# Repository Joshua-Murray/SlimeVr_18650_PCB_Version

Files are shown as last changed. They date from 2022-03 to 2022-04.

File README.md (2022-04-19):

# SlimeVr_18650_PCB_Version
This repository contains all the files for the PCB and the case designed with this PCB in mind. It also contains a detailed instructions on the assembly of the PCB and the case.

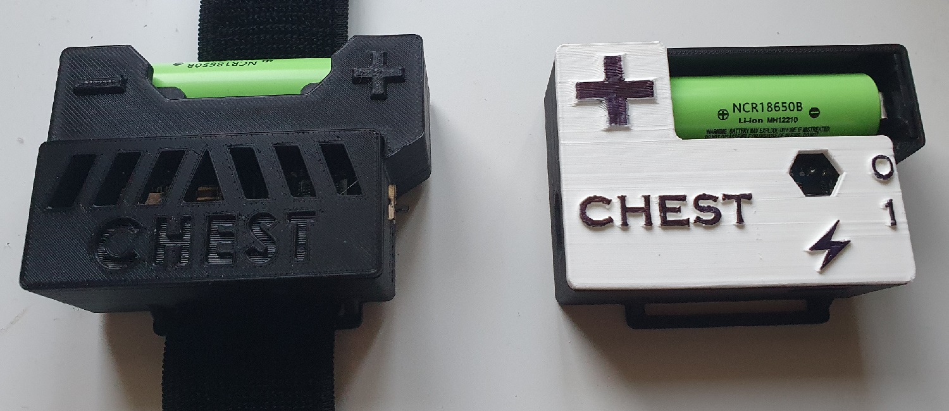
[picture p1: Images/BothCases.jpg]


# Sections
-   Parts and Setup
-   PCB Related Information
- 	Case Related Information
- 	Assembly Information

# Parts and Setup
The parts used for this PCB can be found in the [official Components list](https://docs.slimevr.dev/diy/components-guide.html) and [Schematic](https://docs.slimevr.dev/diy/tracker-schematics.html).
This PCB is compatible with any 3.3V IMU which is smaller than the following maximum dimensions 28mm by 18mm.
The following parts are used in the PCB:
- D1 Mini.
- TP4056 Charge Board (Any connection).
- SPDT Slide Switch (SS12D00G3).
- Any 3.3V IMU under the max dimension 28mm by 18mm.
- 1N5817 Charge Diodes.
	Note for those not using it: Bridge the diode connections from the  positive output to the centre connections.
- (Optional) 180K Ohm resistor for battery sense.
- 3.7V Battery.

For those who who want a case and are using 18650 batteries for the tracker, there are 2 cases using this PCB found in the case files folder. (Additional information below)

# PCB Related Information
The Gerbal file for the PCB can be found in the PCB files folder along with an image of the schematic.
Additionally the project for this PCB can be found at the following links with or without the Aux connector:

PCB with Aux connection: https://easyeda.com/editor#id=22acdfc2081e44a4a4d110a4ab3e7e97

PCB without Aux connection: https://easyeda.com/editor#id=266cc1c912134b10b92cc5d7d849ca76

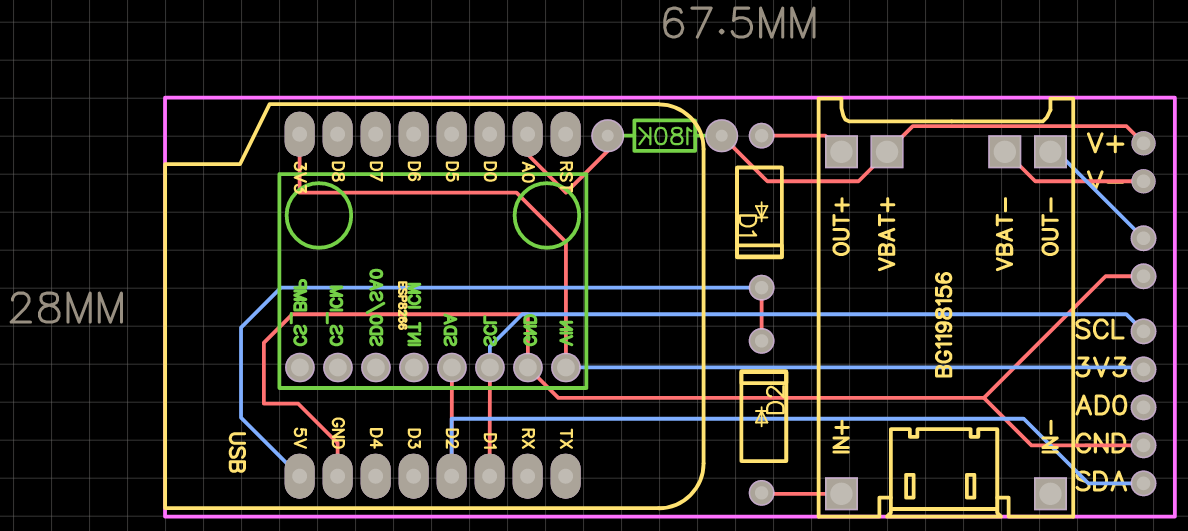
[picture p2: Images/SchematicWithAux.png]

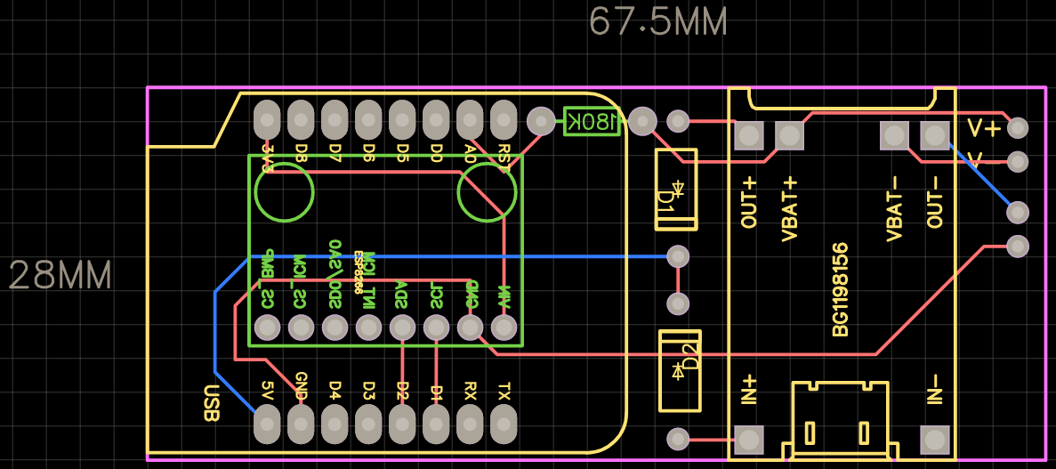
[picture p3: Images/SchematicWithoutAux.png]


## PCB Ordering
The steps for ordering a PCB is very simple and straight forward as seen below.
- Step 1: Download the Gerbal files for the PCB of your choice.
- Step 2: Go to a PCB manufacturing site, for demonstration purposes JLCPCB will be used found here: https://jlcpcb.com/

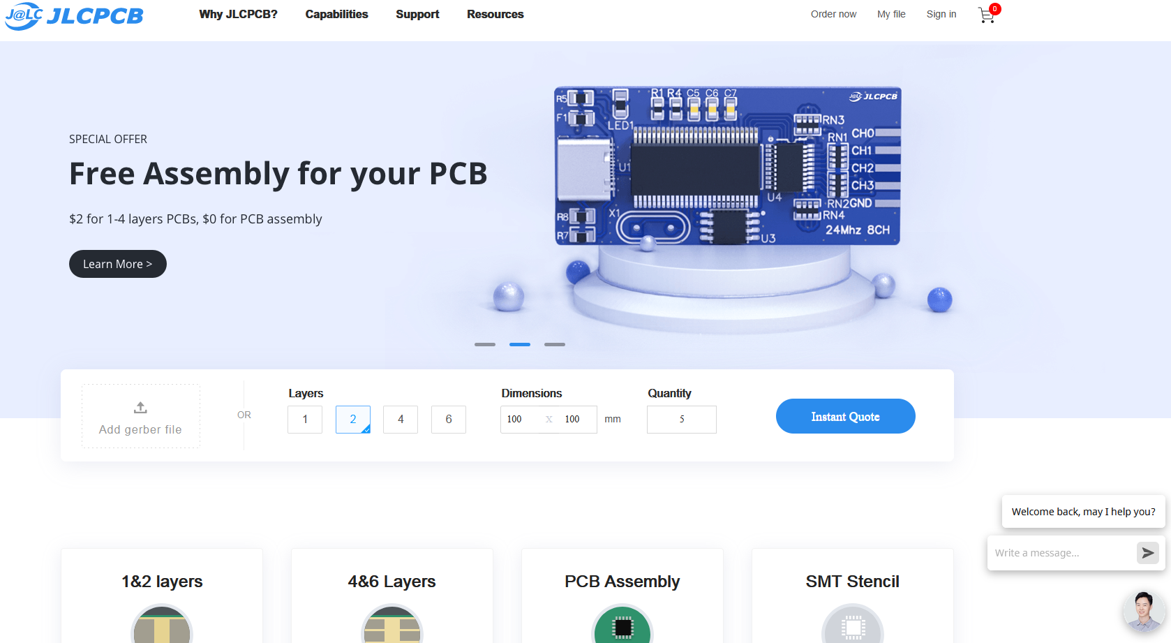
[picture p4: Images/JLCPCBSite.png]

- Step 3: Upload the Gerbal zip file.
- Step 4: Inspect the following settings are correct (see image) and adjust any of the cosmetic options to your preference.

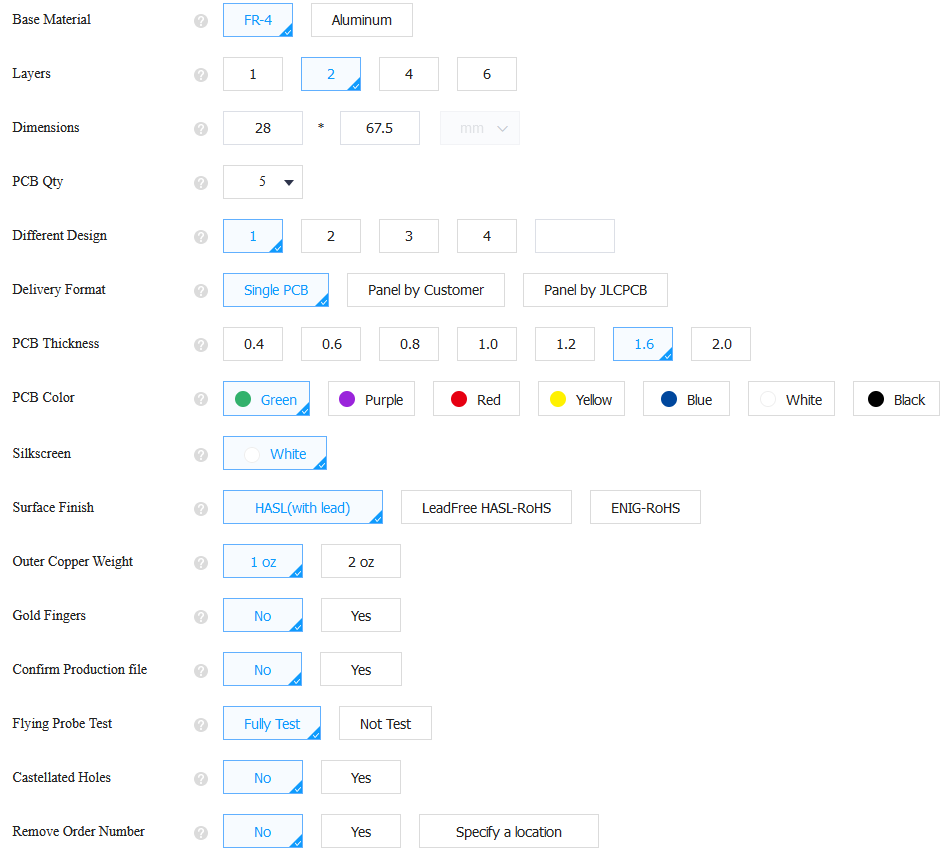
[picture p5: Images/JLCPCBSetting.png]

- Step 5: Pay and wait for it to arrive.

# Case Related Information
This section referes to the cases designed for the PCB and found in the Case files folder. Both of the cases have been designed in SolidWorks.

## Case V:
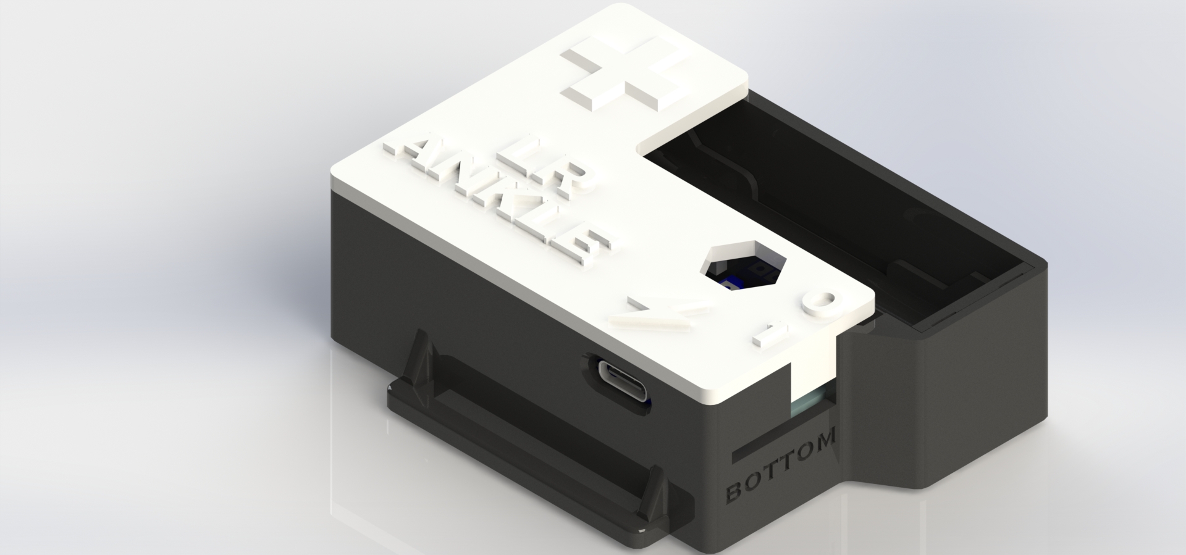
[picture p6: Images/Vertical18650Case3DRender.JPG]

The STL files for 3D printing this case can be found in the "Case Files / Vertical 18650 Battery Mount" folder along with the original files for easy modifications if you choose to do so.

## Case H:
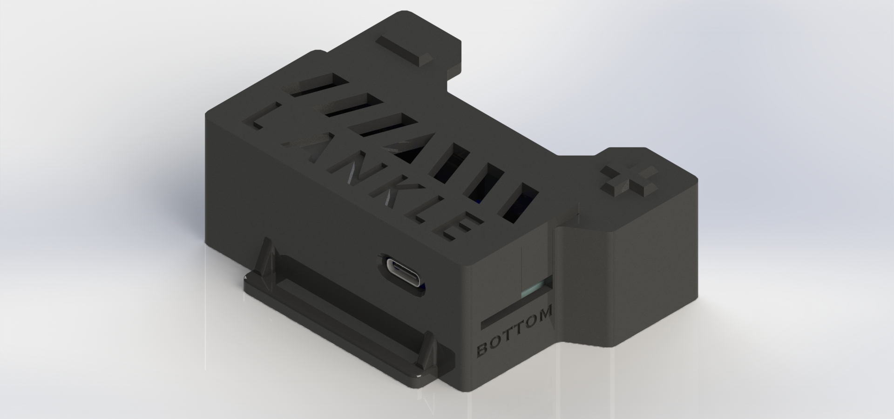
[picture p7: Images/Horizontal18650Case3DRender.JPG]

The STL files for 3D printing this case can be found in the "Case Files / Horizontal 18650 Battery Mount" folder along with the original files for easy modifications if you choose to do so.

## Extension:
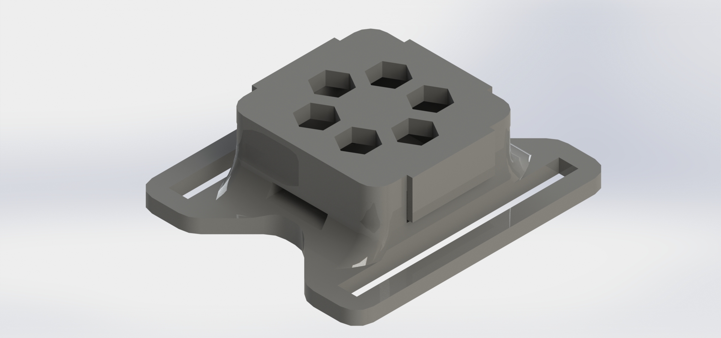
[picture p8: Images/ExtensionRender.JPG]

The STL files for 3D printing this case can be found in the "Case Files / Extension Case" folder along with the original files for easy modifications if you choose to do so.
Note: This extension case is compatible with all IMUs within 28mm by 18mm dimensions, if there are request for larger IMUs they would be added.

## 3D printing the case
The following demonstration for preparing each STL file will be shown in PrusaSlicer, ensure that the if there is supports used to match the images provided.
All of the case files can be printed at 0.2mm layer height.

- For the vertical battery mount case model use supports where the Aux cables exit the case.
- For the lid model, use supports for all overhanging material.

- For the horizontal battery mount case model use supports where the Aux cables exit the case and where the 18650 battery holder will be held.
- For the horizontal lid model, does not require any support material.

- The Extension models does not require any support material.

PCB Assembly Instructions
For the instructions below MPU6050 will be used, however any IMU using 3.3V input, match the first 4 pins and within 28mm by 18mm. Diodes are not required but the positive output must be bridged with a wire.
The battery sense resistor is optional, within this instructions a higher watt resistor will be used, 1/4 watt also works.

Below are all the electrical parts required to build a tracker, the parts within the marked area are for the extension tracker.
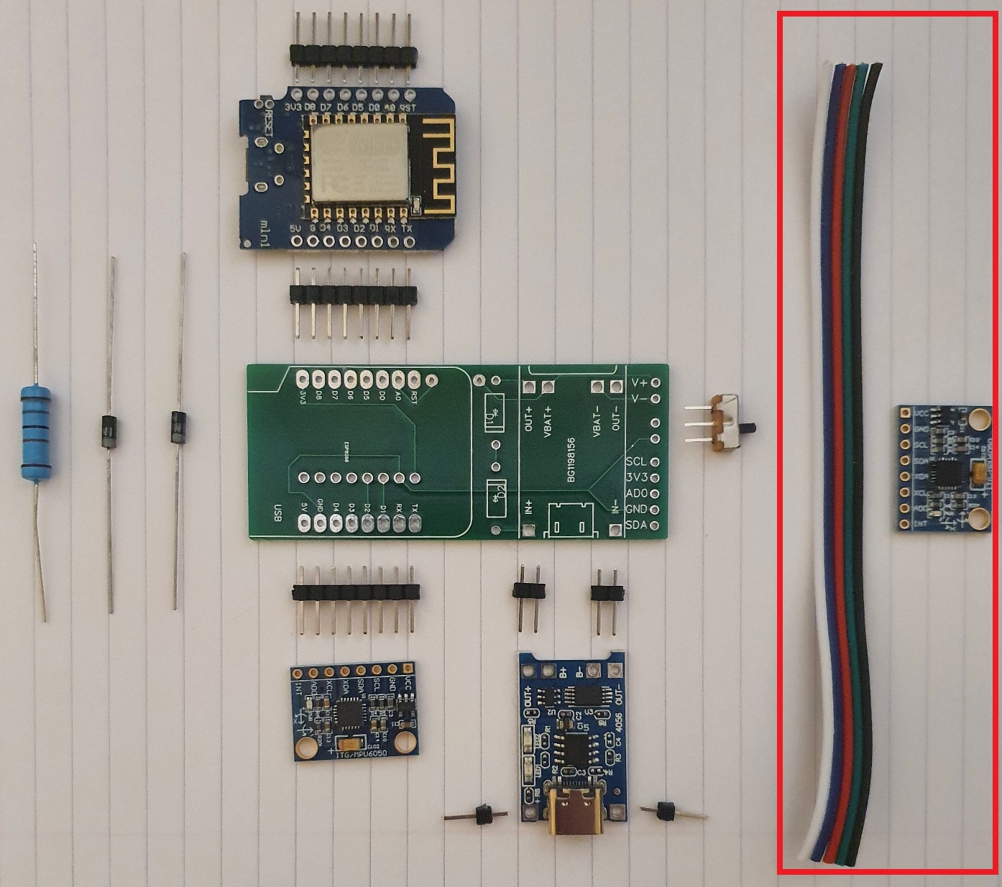
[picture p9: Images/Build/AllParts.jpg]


Step 1:

Solder the diodes in their spaces as shown in the picture (Grey strip pointing to the centre) and cut off the excess.

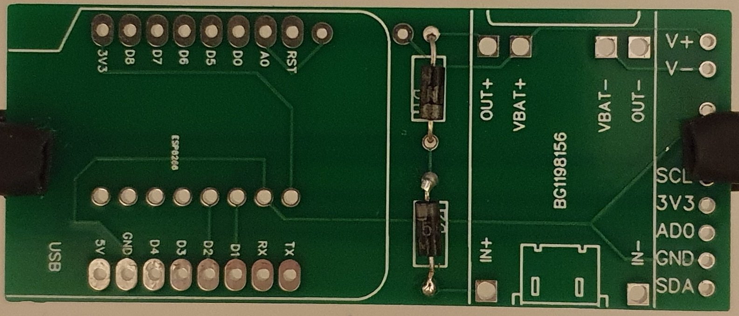
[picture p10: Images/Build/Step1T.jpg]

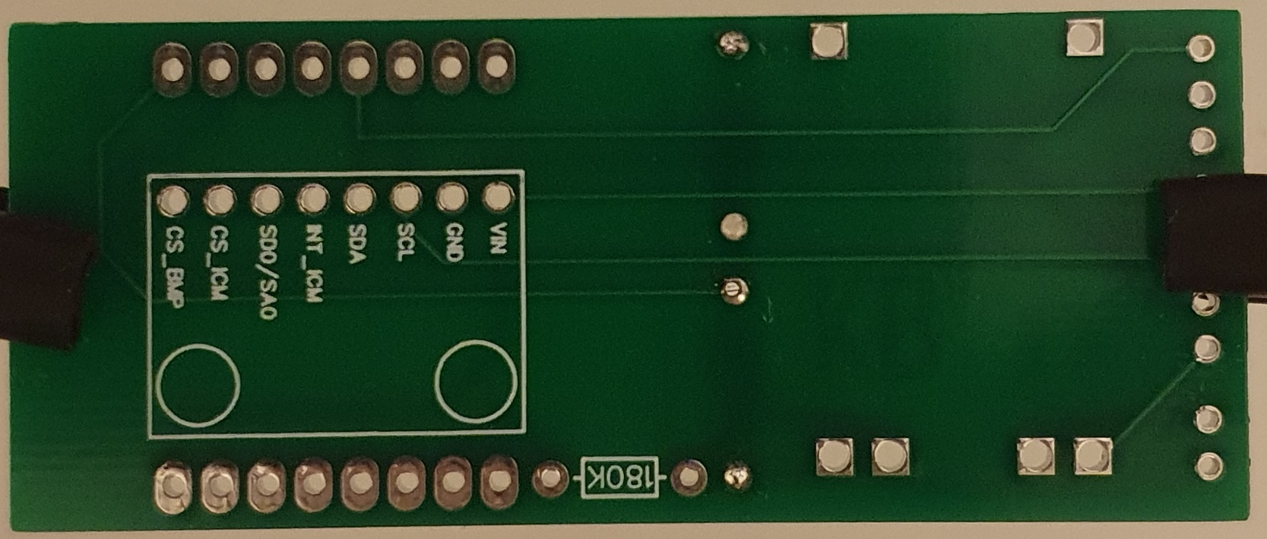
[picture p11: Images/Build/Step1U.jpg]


Step 2:

Solder the pins used for the TP4056 in the spaces as shown in the picture.

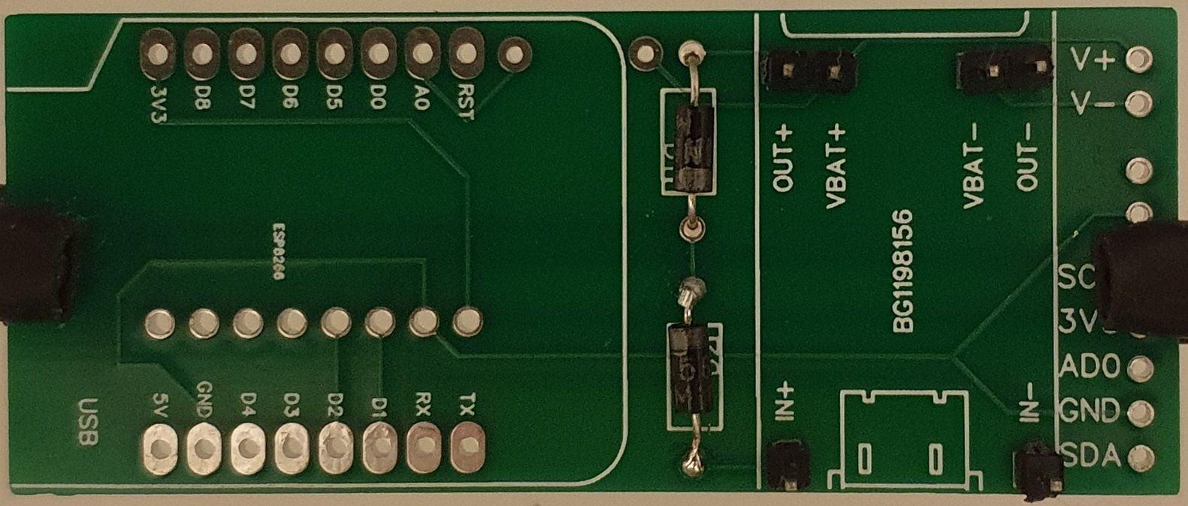
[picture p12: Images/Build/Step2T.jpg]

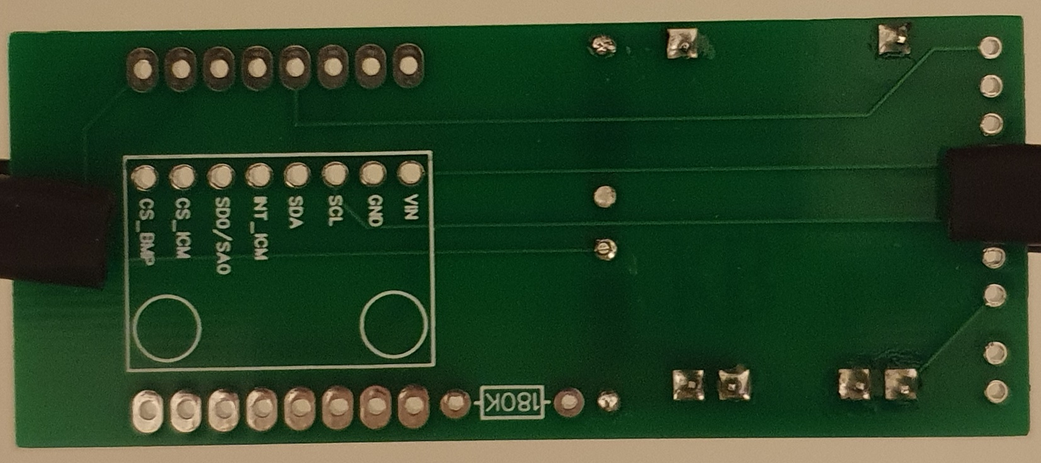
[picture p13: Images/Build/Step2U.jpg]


Step 3:

Solder the TP4056 on the pins from step 2 as shown in the picture and cut off the excess.

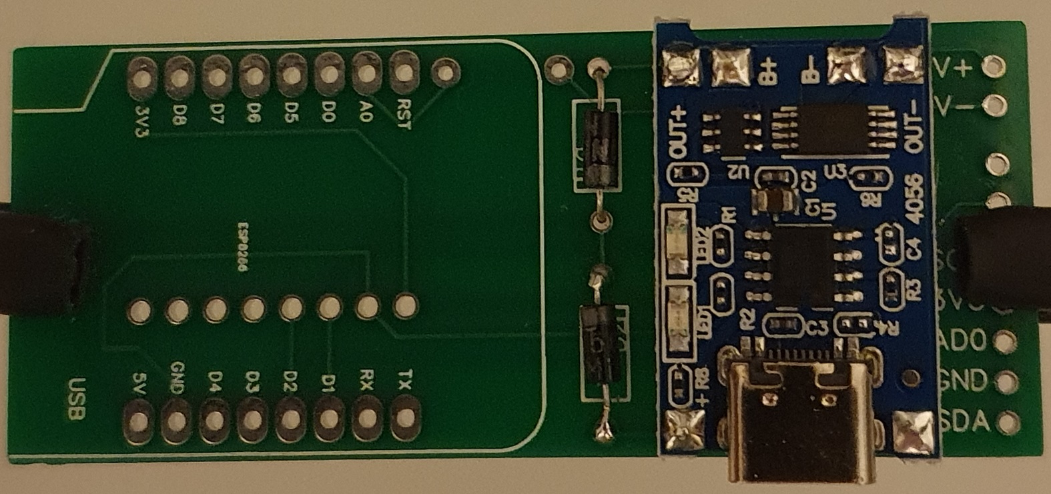
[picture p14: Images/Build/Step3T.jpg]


Step 4:

Solder the pins used for the D1 Mini in the spaces as shown in the picture.

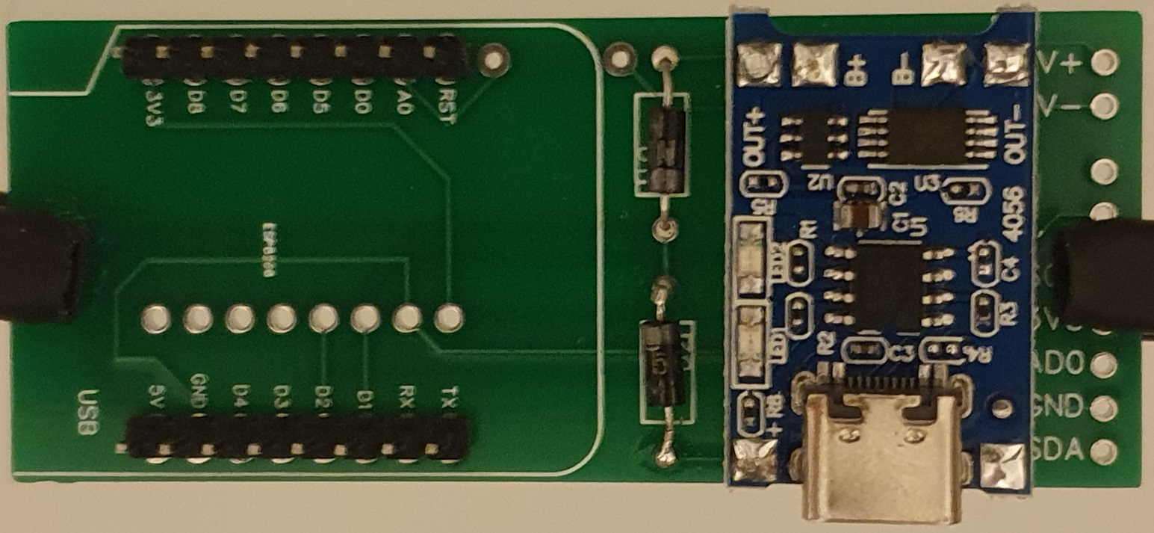
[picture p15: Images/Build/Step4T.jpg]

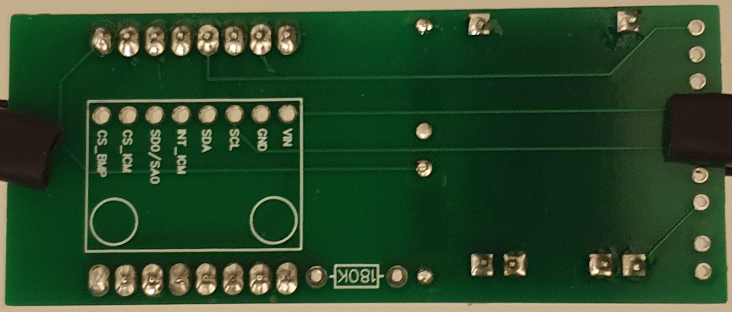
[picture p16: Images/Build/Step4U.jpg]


Step 5:

Solder the pins used for the IMU in the spaces as shown in the picture only VCC, GND, SCL, SDA are required, the rest are optional.

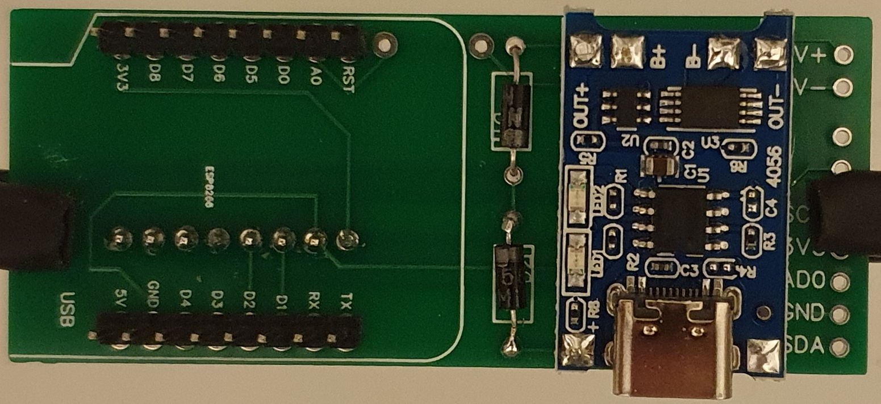
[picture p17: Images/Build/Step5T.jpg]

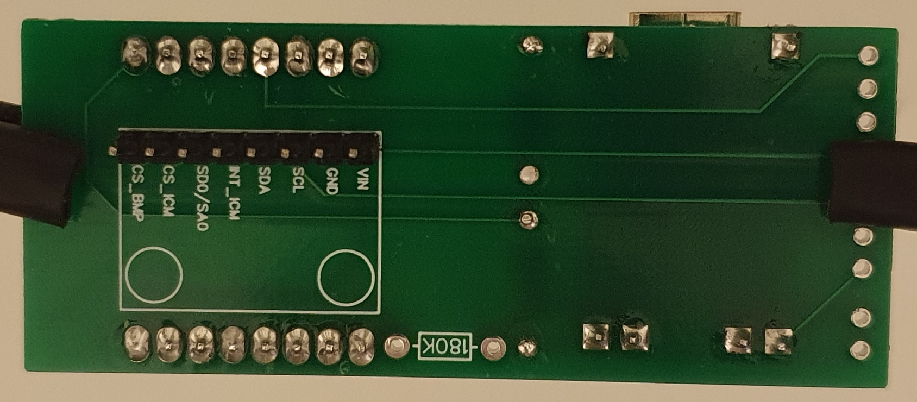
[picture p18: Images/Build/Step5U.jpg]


Step 6 - OPTIONAL:

Solder the battery sense 180K Ohm resistor in the space shown in the picture and cut off the excess.

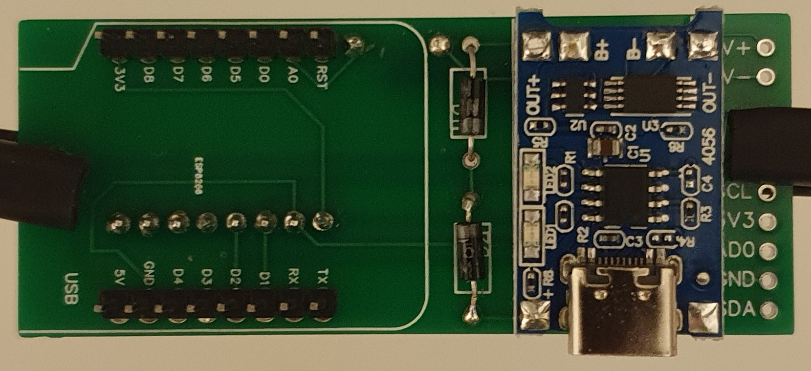
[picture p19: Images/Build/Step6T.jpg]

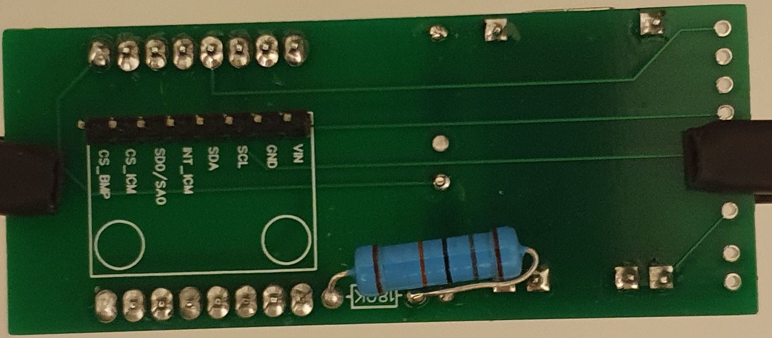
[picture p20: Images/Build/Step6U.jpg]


Step 7:

Solder the D1 Mini on the pins from step 4 as shown in the picture and cut off the excess.

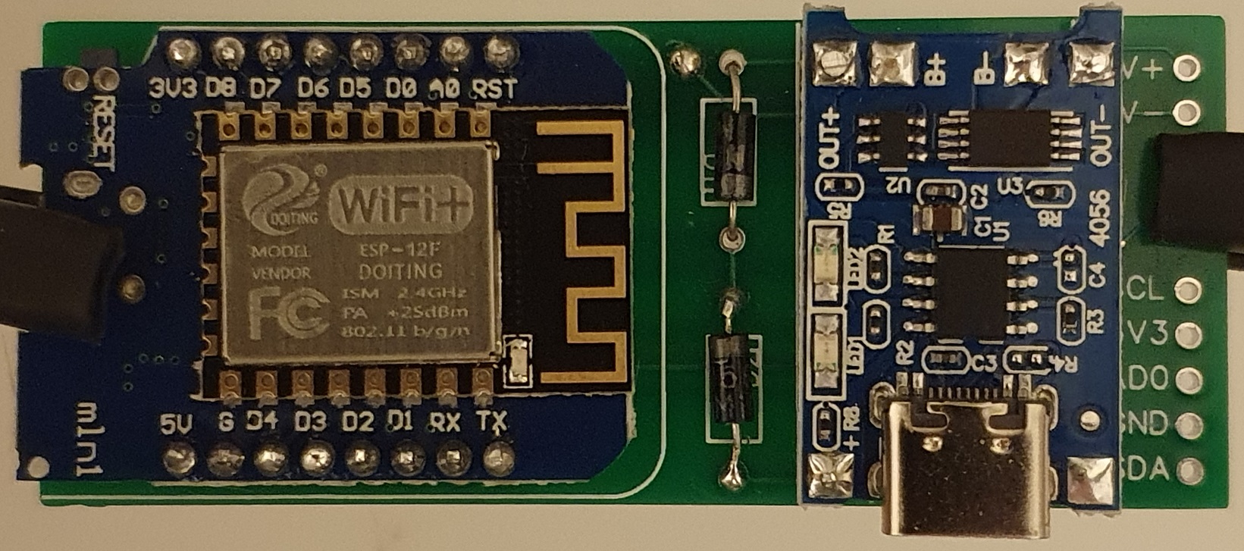
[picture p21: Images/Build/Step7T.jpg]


Step 8:

Solder the IMU on the pins from step 5 as shown in the picture and cut off the excess. Ensure that the IMU remains parallel to the PCB, this could be achieved by using unused pin headers.

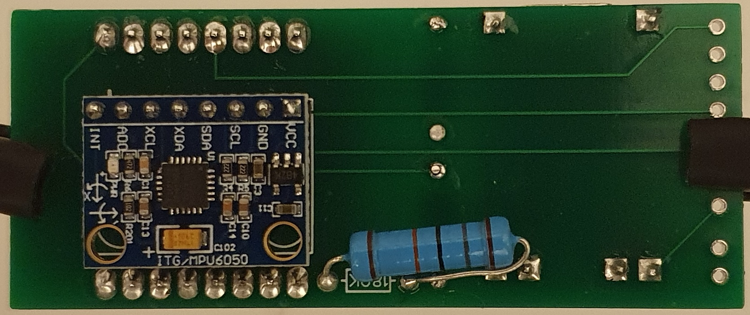
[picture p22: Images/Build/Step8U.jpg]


Step 9:

Cut one of the outside pins of the switch and then bend the remaining two in as shown in the picture.

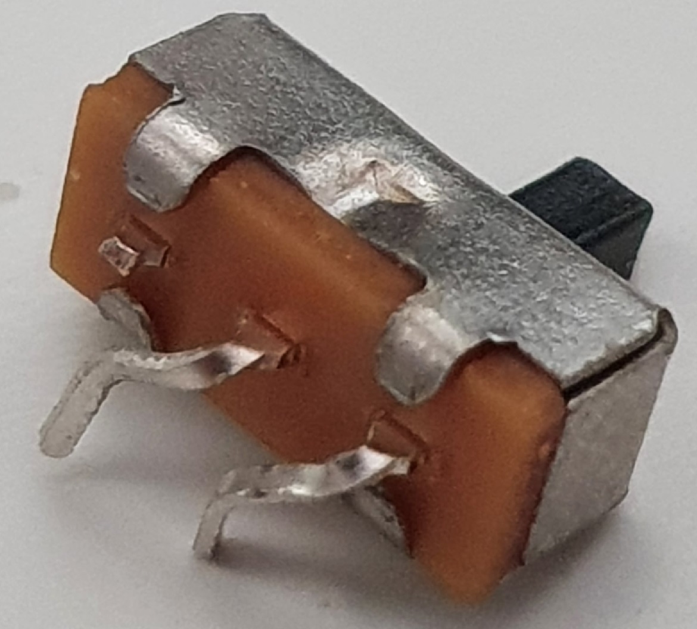
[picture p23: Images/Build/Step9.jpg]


Step 10A - Horizontal 18650 case OPTION 1:

Solder a wire onto each the positive and negative terminals, ensure that the wire for the negative terminal is longer as it will be weaved into the case as shown in the picture, recommended length: Positive 40mm and Negative 90mm. You can coil the positive and negative wire after if you wish to do so. Cut off excess, leave enough wire for moving the PCB when it is attached.

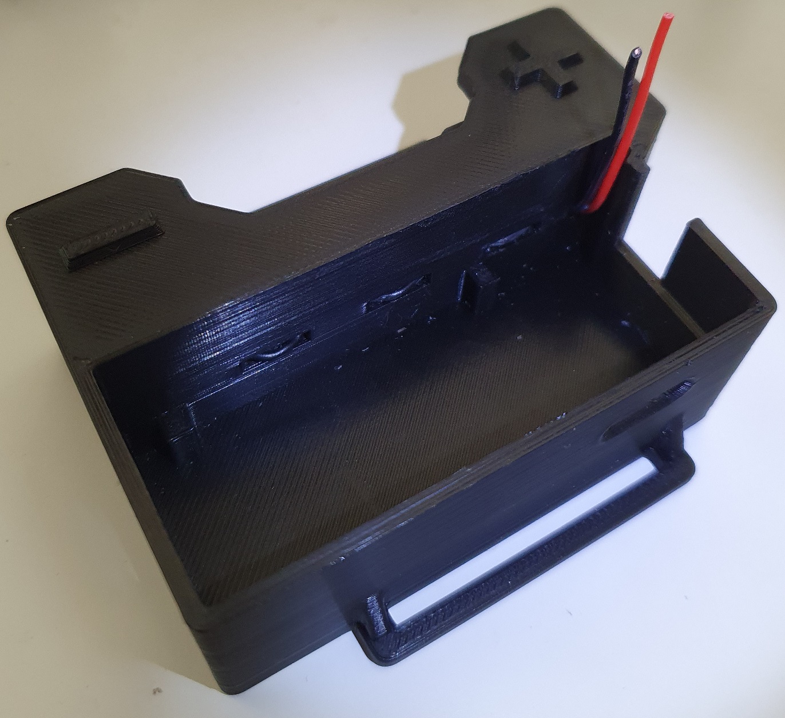
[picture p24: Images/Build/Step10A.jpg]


Step 10B - Vertical 18650 case OPTION 2: 

Solder a wire onto each the positive and negative terminals, ensure that the wire for the positive terminal is longer so it could reach the PCB, recommended length: Positive 90mm and Negative 40mm. You can coil the positive and negative wire after if you wish to do so. Cut off excess, leave enough wire for moving the PCB when it is attached.

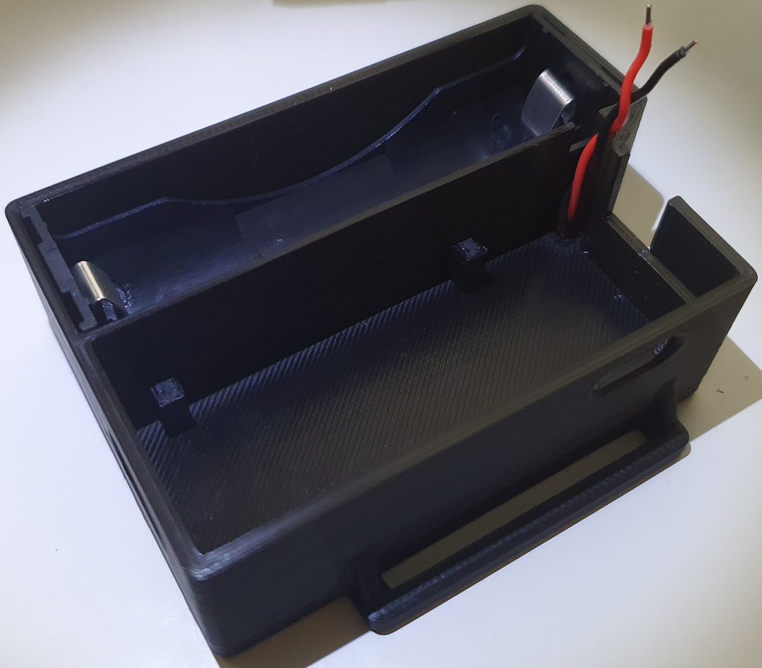
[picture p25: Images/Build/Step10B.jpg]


Step 11 - OPTIONAL EXTENSION:

Solder wires used for the extension tracker as shown in the picture, leave enough wire for movement between trackers. 

Note: Ensure that the ADO is bridged to the 3v3 pin for the extension IMU and ADO bridged to GND for the main IMU the or do so on the IMU side in step 14.

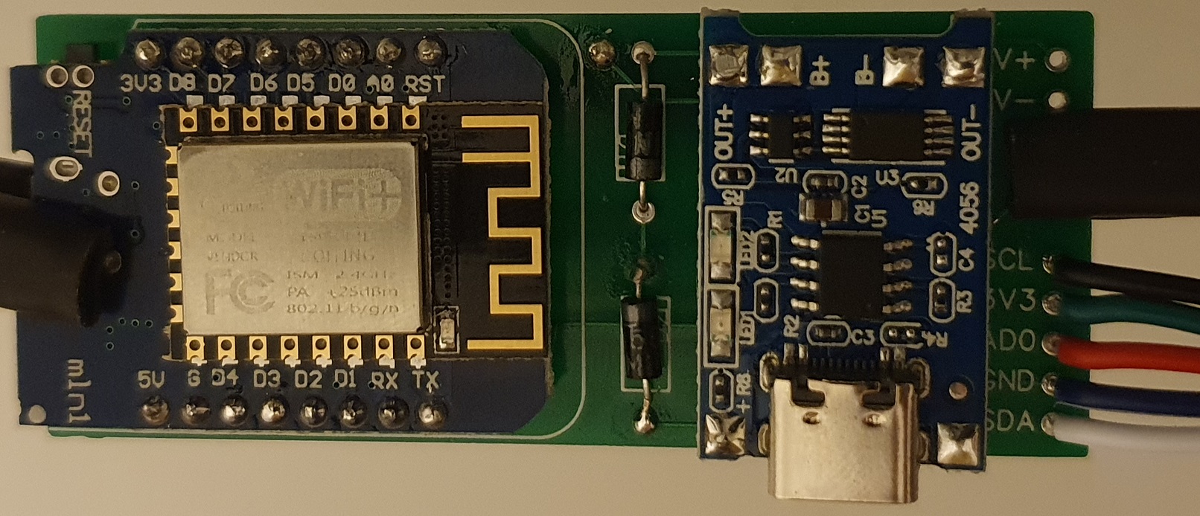
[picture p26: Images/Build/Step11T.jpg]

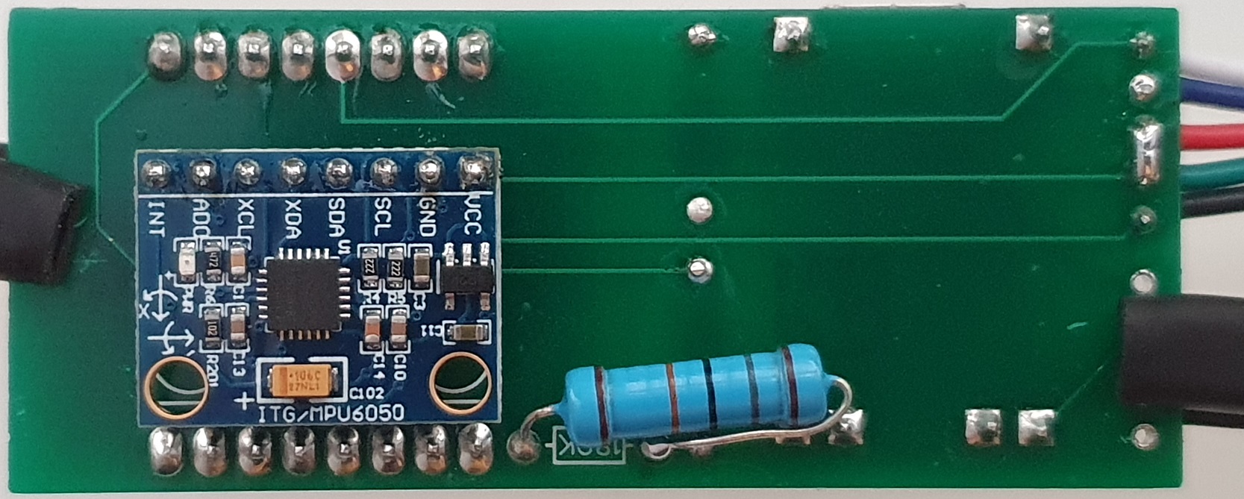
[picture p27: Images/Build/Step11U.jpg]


Step 12:

Note: If there is a extension tracker cables first move them into the slot in the case - the smaller one next to where the switch location.

Insert the PCB into the case, start with the moving TP4056 into its slot and ensure that the batteries wires don't disconnect once the PCB is completely flat inside move on to the next step. This is the same for both cases

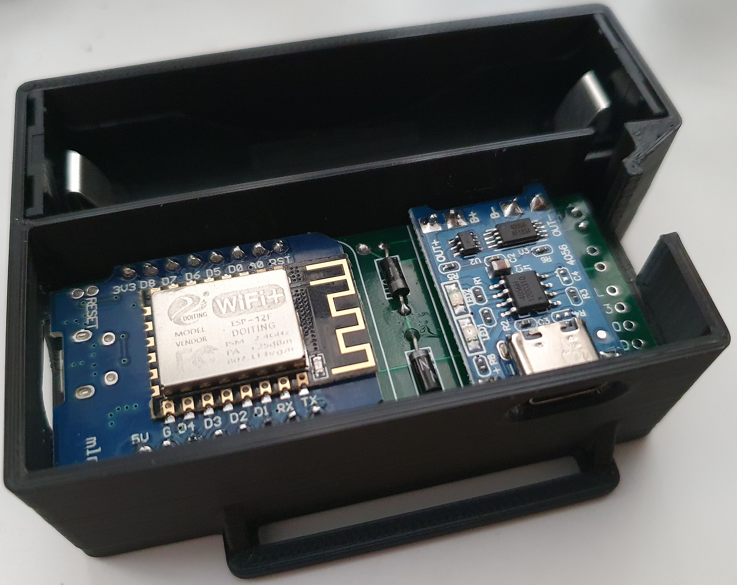
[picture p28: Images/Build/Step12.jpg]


Step 13:

Insert the switch prepared in step 9 into the slot in the case and adjust the pins to go into the PCB holes as shown in the picture. Once satisfied, solder the switch. Put on the corresponding tracker position lid to complete the main unit.

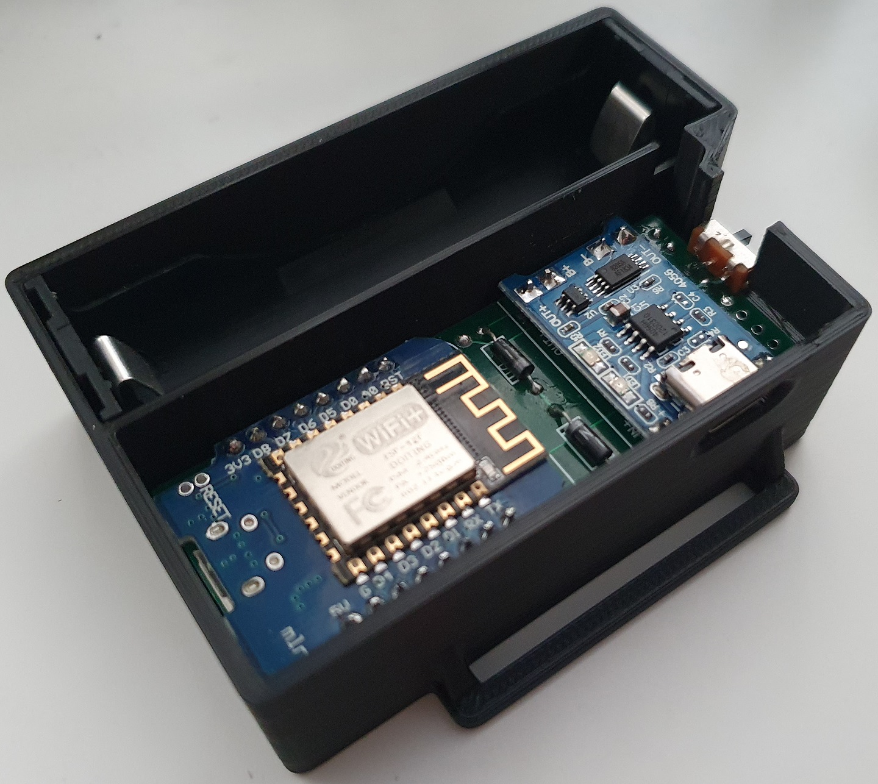
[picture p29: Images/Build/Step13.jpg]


Step 14 - OPTIONAL EXTENSION: 

Using the wires from step 11, put it through the slot in the extension and continue to do so leaving enough room to solder the corresponding wires to the pins of the IMU as shown in the picture.

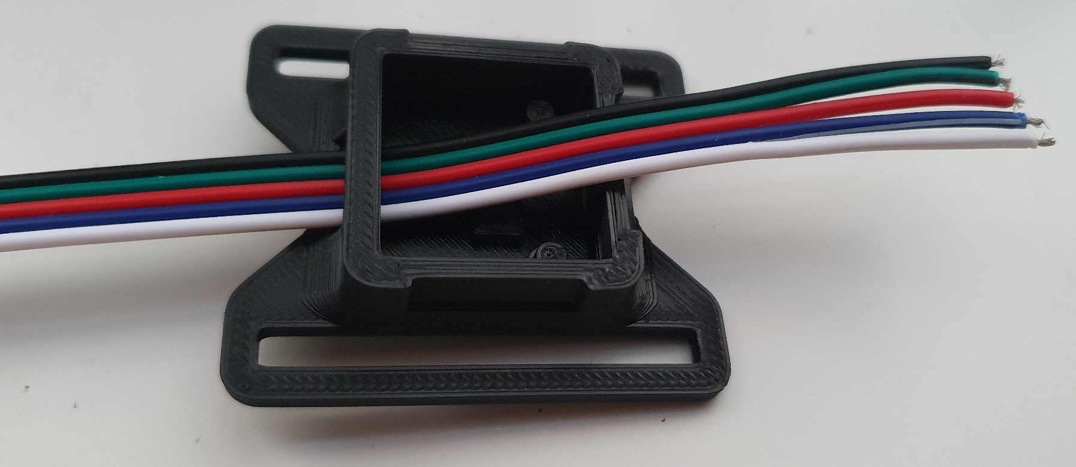
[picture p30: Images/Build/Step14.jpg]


Step 15 - OPTIONAL EXTENSION:

Solder the corresponding wires to the pins of the IMU as shown in the picture - on the underside of the IMU.
Note: Ensure that the ADO is bridge to the 3v3 pin if it has not been done in step 11.

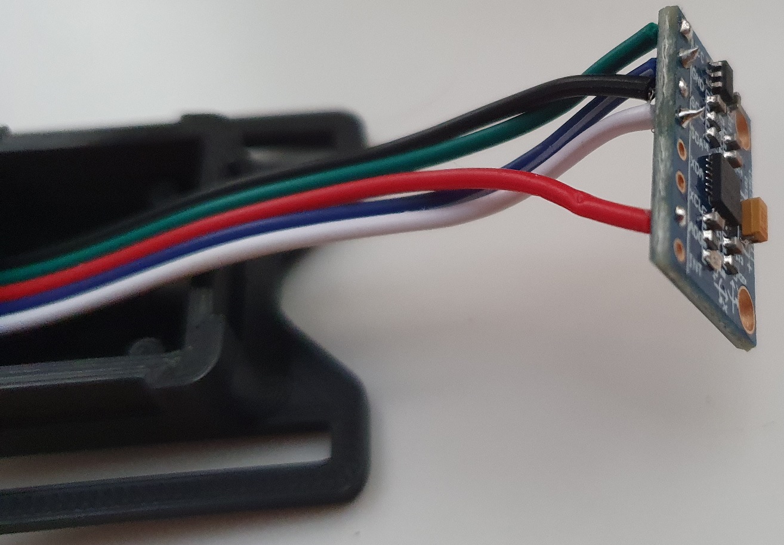
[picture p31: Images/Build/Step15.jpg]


Step 16 - OPTIONAL EXTENSION:

Carefully position the IMU into the extension case, once positioned push it down onto the pins, gently pull cables when required, the IMU should be sitting inside as shown in the picture. Once it is in fully put on the extension lid on to finish the assembly.

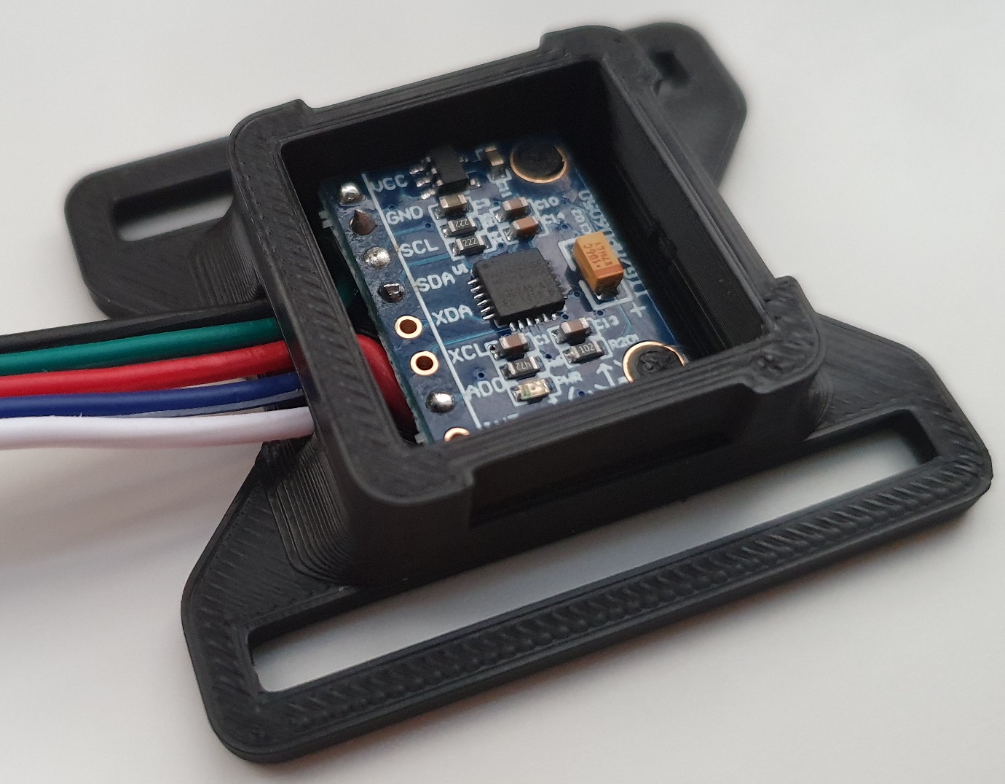
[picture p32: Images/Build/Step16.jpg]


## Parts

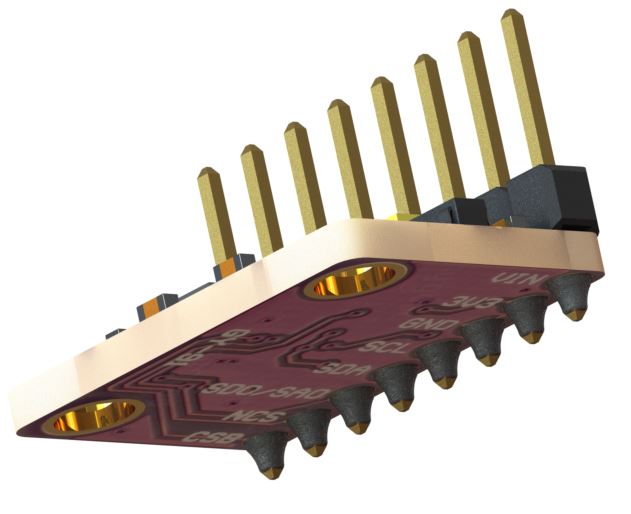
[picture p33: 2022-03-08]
Case Files/Electronic PlaceHolder Parts/GY-91/Renders/GY-91 bot - pins up.JPG

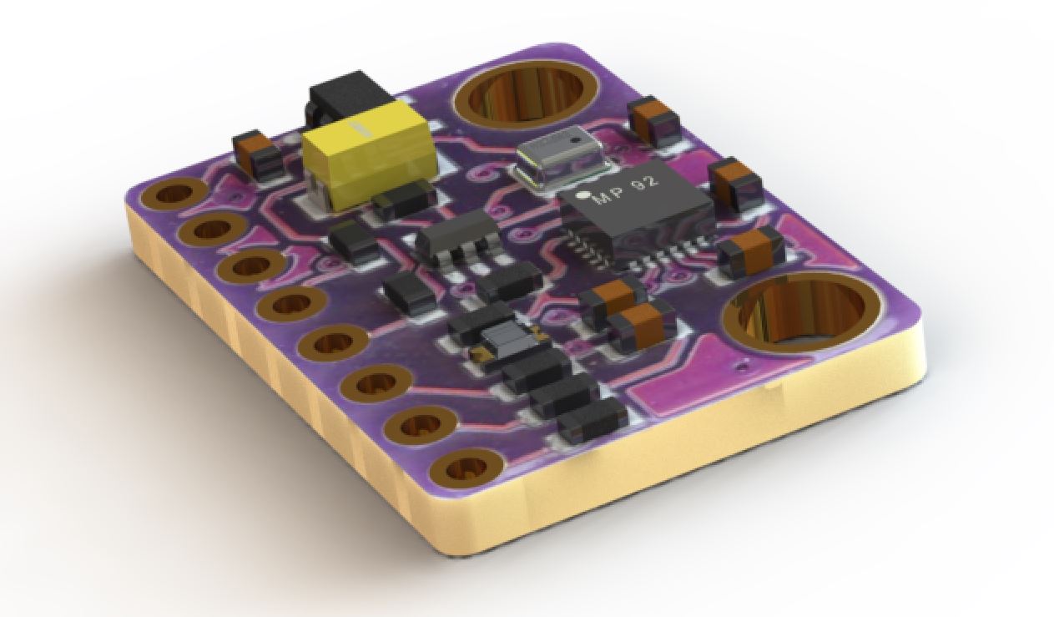
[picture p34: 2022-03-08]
Case Files/Electronic PlaceHolder Parts/GY-91/Renders/GY-91 top - no pins.JPG

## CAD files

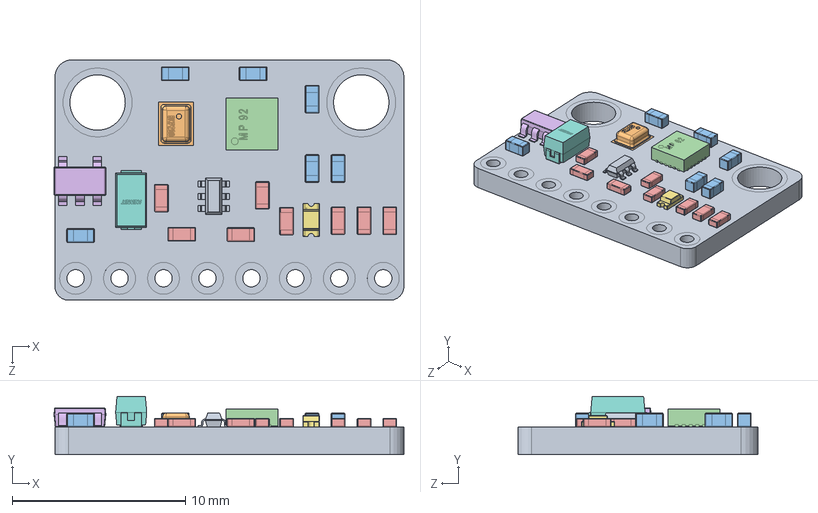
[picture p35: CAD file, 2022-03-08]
Case Files/Electronic PlaceHolder Parts/GY-91/GY-91_MPU9250+BMP280 - Basic.SLDASM
20.2 x 3.37 x 13.9 mm
GY-91 Base
BMP280
cap_603 x 6
MPU9250
res_603 x 8
SOT23-5
Surface Mount Chip LED 3.2x1.6mm
T10uF
SOT23-6-1

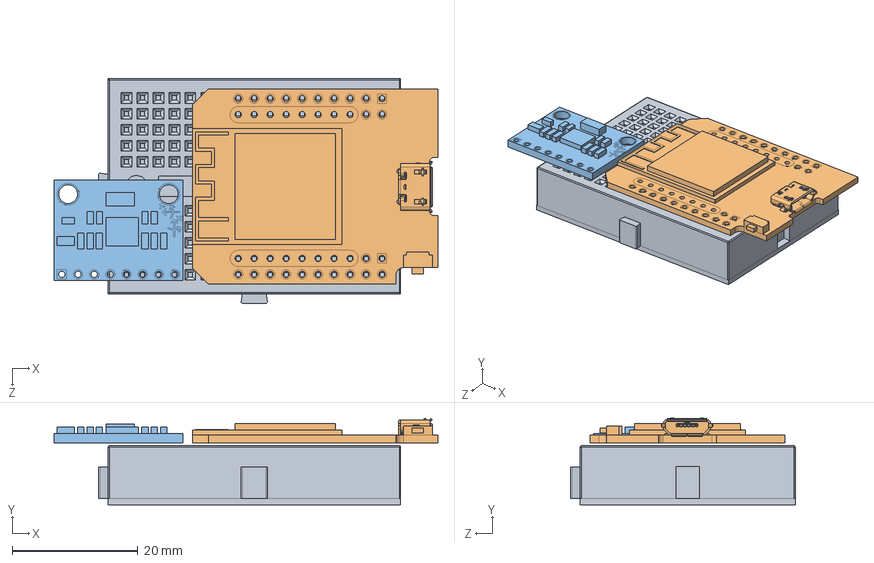
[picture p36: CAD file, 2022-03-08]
Case Files/Electronic PlaceHolder Parts/MPU_MICRO.SLDASM
61.1 x 13.8 x 35.7 mm
Mini-Black Breadboard
Wemos-Mini-D1-ESP32
pcb.step

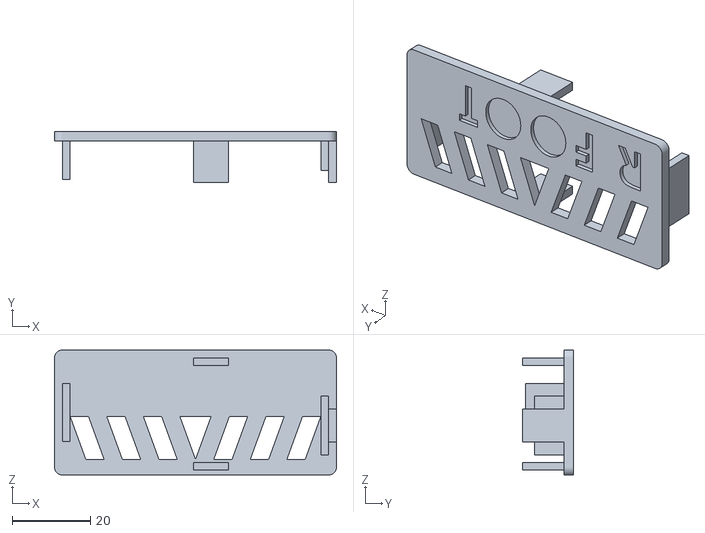
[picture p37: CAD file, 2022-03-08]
Case Files/Horizontal 18650 Battery Mount/_Main_Body_Lid_RFoot.STL
72.1 x 13.1 x 32.0

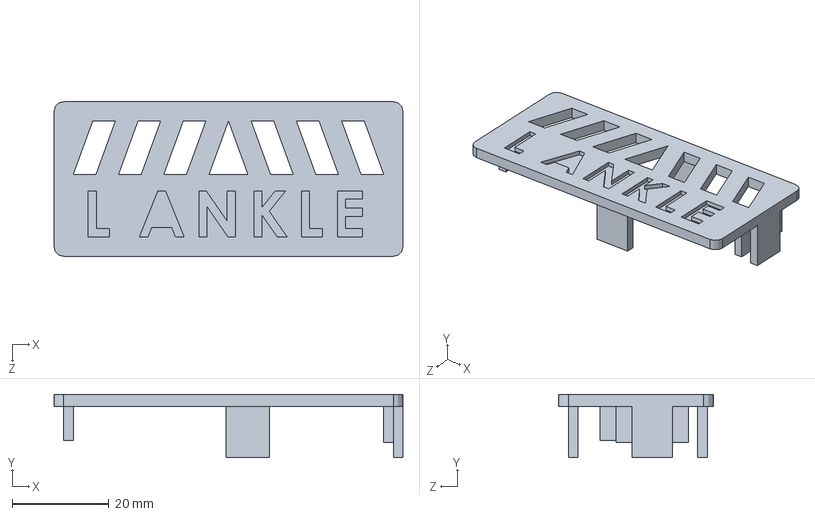
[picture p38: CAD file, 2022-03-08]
Case Files/Horizontal 18650 Battery Mount/Original Files/Main_Body_Lid.SLDPRT
72.1 x 13.1 x 32.0 mm

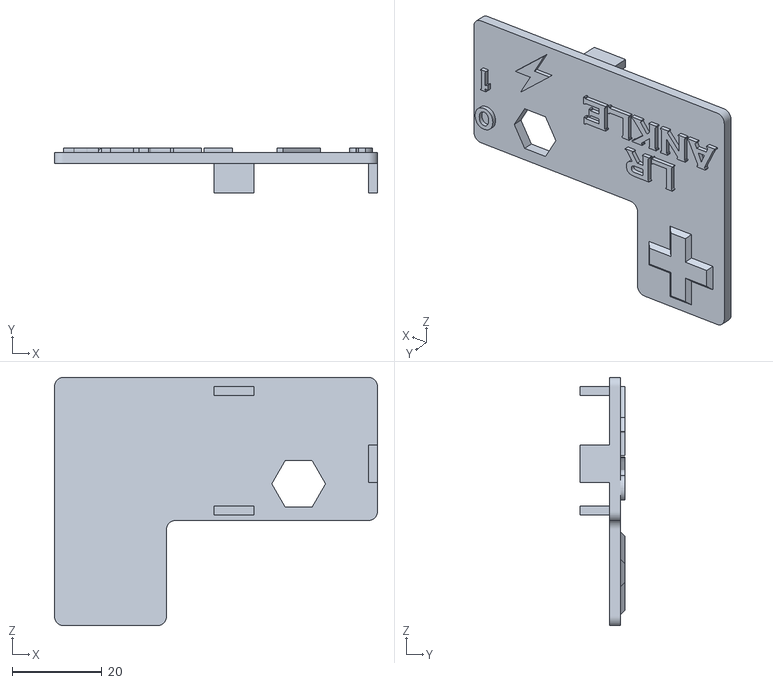
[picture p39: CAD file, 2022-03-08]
Case Files/Vertical 18650 Battery Mount/Main_Body_Lid_Ankle.STL
72.1 x 10.1 x 55.4

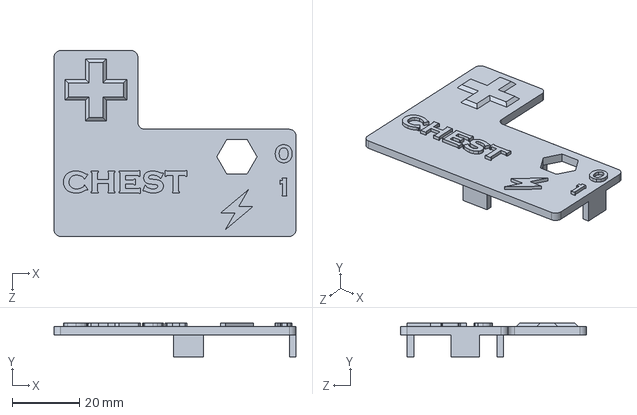
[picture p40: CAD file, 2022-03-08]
Case Files/Vertical 18650 Battery Mount/Original Files/Main_Body_Lid_Chest.SLDPRT
72.1 x 10.1 x 55.4 mm

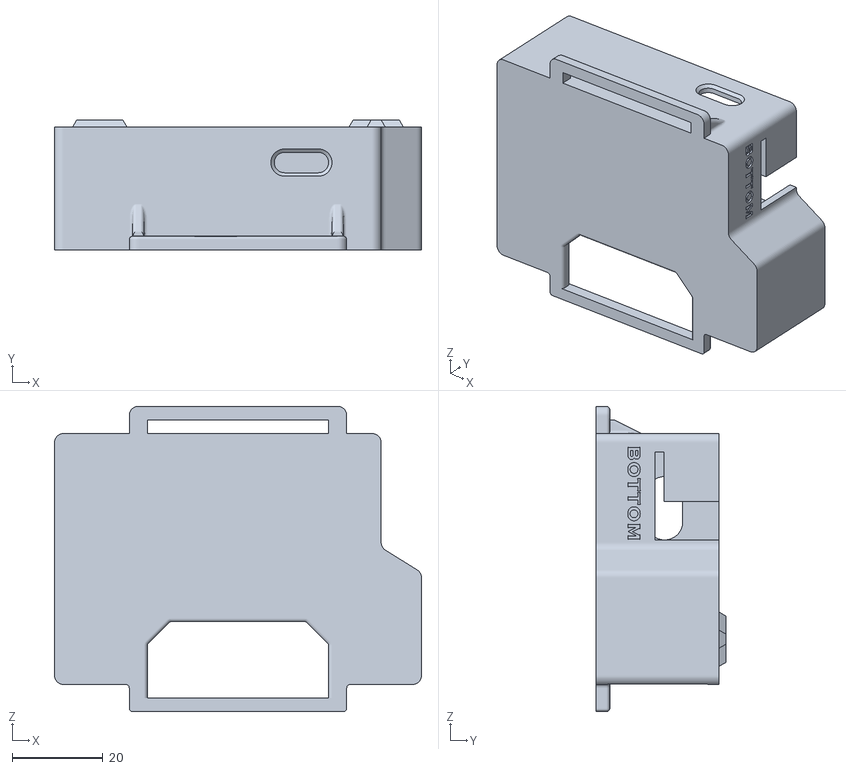
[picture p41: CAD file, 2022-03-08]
Case Files/Horizontal 18650 Battery Mount/_Main_Body.STL
81.0 x 28.6 x 67.4

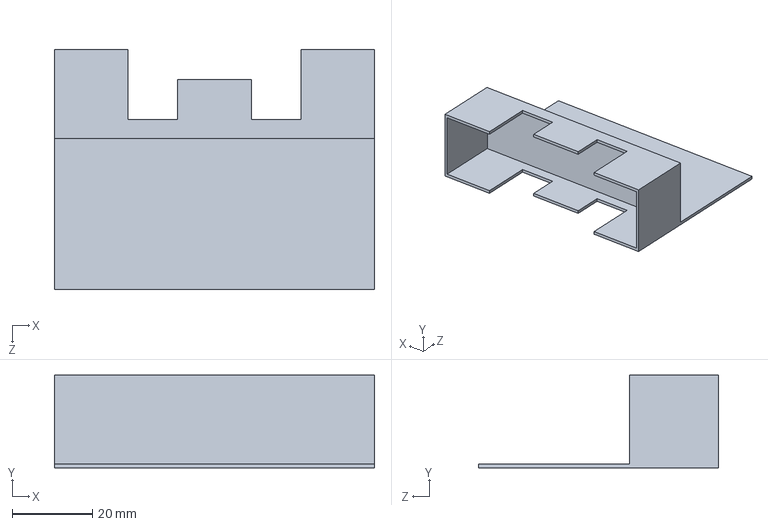
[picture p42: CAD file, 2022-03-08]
Case Files/Horizontal 18650 Battery Mount/Original Files/Main_Body_Battery_Holder.SLDPRT
80.0 x 23.2 x 60.0 mm

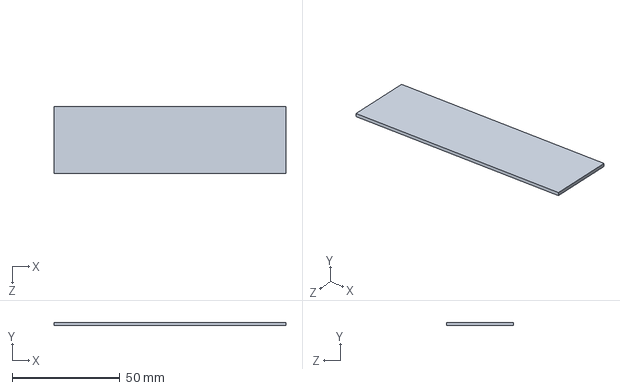
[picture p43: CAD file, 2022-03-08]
Case Files/Horizontal 18650 Battery Mount/Original Files/Main_Body_Electronics.SLDPRT
107.6 x 1.50 x 31.0 mm

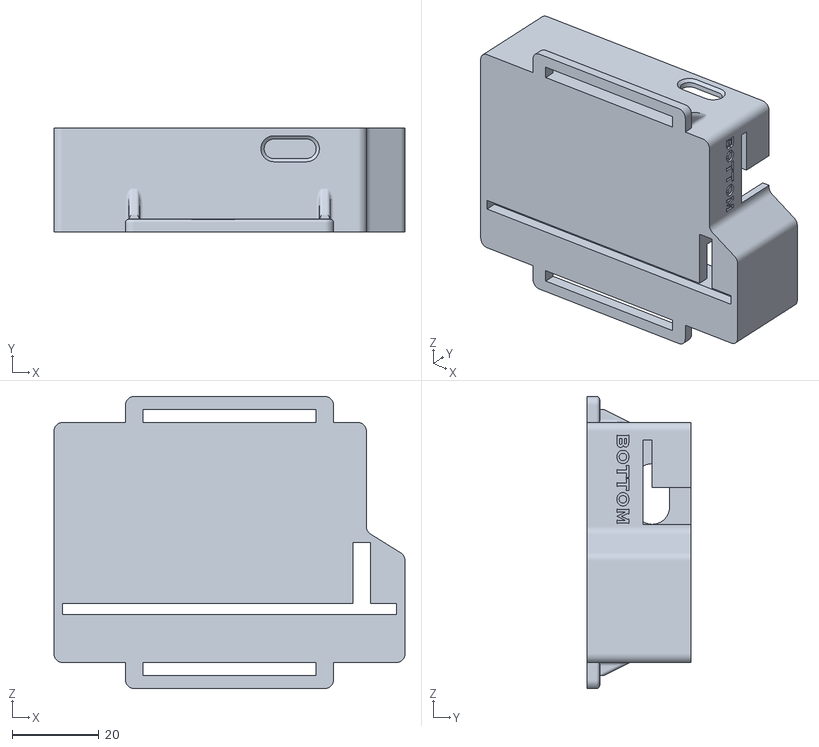
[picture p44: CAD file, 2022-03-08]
Case Files/Vertical 18650 Battery Mount/Main_Body.STL
81.0 x 24.1 x 67.4

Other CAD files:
Case Files/Vertical 18650 Battery Mount/Original Files/Main_Body_Lid_Knee.SLDPRT
Case Files/Horizontal 18650 Battery Mount/_Main_Body_Lid_Chest.STL
Case Files/Vertical 18650 Battery Mount/Original Files/Main_Body.SLDPRT
Case Files/Horizontal 18650 Battery Mount/_Main_Body_Lid_LKnee.STL
Case Files/Horizontal 18650 Battery Mount/Original Files/Main_Body.SLDPRT
Case Files/Vertical 18650 Battery Mount/Original Files/Main_Body_Lid_Ankle.SLDPRT
Case Files/Horizontal 18650 Battery Mount/_Main_Body_Lid_Hip.STL
Case Files/Vertical 18650 Battery Mount/Main_Body_Lid_Chest.STL
Case Files/Electronic PlaceHolder Parts/18650_Battery_Holder.SLDASM
Case Files/Electronic PlaceHolder Parts/Battery.SLDPRT
Case Files/Electronic PlaceHolder Parts/GY-91/Components/BMP280.SLDPRT
Case Files/Electronic PlaceHolder Parts/GY-91/Components/Backup (1) of BMP280.SLDPRT
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

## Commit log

2022-03-08 Add files via upload
    Initial file upload
    [18650_Battery_Holder.SLDASM, BMP280.SLDPRT, Backup (1) of BMP280.SLDPRT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]
2022-03-08 Update README.md
    Added PCB links (will be moved later)
